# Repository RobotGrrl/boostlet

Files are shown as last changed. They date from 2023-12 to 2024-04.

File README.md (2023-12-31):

# Boostlet!

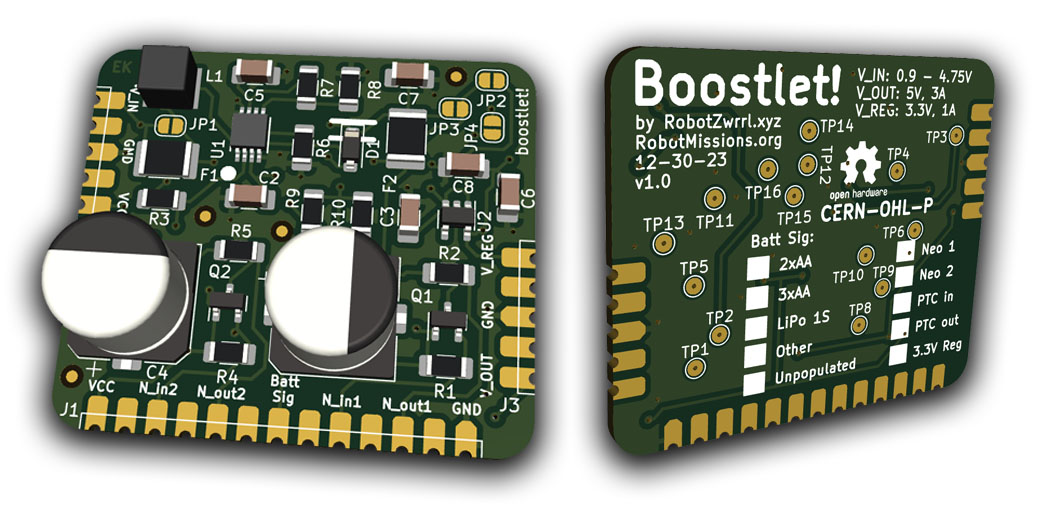
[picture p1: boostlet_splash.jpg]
Boostlet! board 3d view front and back


Embeddable circuit board to boost battery input to 5V intended for small robots. Useful access is provided to two logic level convertors for Neopixels, and a 3.3V regulator. Input and output are protected with PTCs, with the option to not populate with a solder jumper. Castellated connectors enable this circuit board to be added either surface mount or with through-hole 0.1" headers. 

---

## Documentation

[Boost IC: PAM2401](https://www.diodes.com/assets/Datasheets/PAM2401.pdf)

Dimensions: 35 mm x 40 mm

- V_IN: 0.9 - 4.75V
- V_OUT: 5V, 3A
- V_REG: 3.3V, 1A

### Connectors

J1
- VCC
- NEO_IN2
- NEO_OUT2
- BATT_SIG
- NEO_IN1
- NEO-OUT1
- GND

J2 (Input)
- V_IN (V_BATT)
- GND
- VCC

J3 (Output)
- V_OUT (5V)
- GND
- V_REG (3.3V)

### Solder Jumpers
- JP1: Bypass input PTC
- JP2: Enable 3.3V reg powered from 5V boost output
- JP3: Bypass output PTC
- JP4: Connect 3.3V reg output to Vcc _(be sure Vcc isn't connected to anything!)_

_Solder jumpers are open by default, add solder to connect the pads to close them_

Documentation provided under [CC-BY-4.0](https://creativecommons.org/licenses/by/4.0/)

---

## License

Boostlet! (C) Copyright Erin RobotZwrrl, Robot Missions Inc.

12-30-23 v1.0

[RobotZwrrl.xyz/boostlet](http://RobotZwrrl.xyz/boostlet)

[RobotMissions.org](https://RobotMissions.org)

This hardware is released under:

CERN Open Hardware License Version 2.0 - Permissive (CERN-OHL-P)

[https://cern-ohl.web.cern.ch/](https://cern-ohl.web.cern.ch/)

Disclaimer: Distributed as is. No warranty is given. Not responsible or liable for any damage or harm that result from this product.

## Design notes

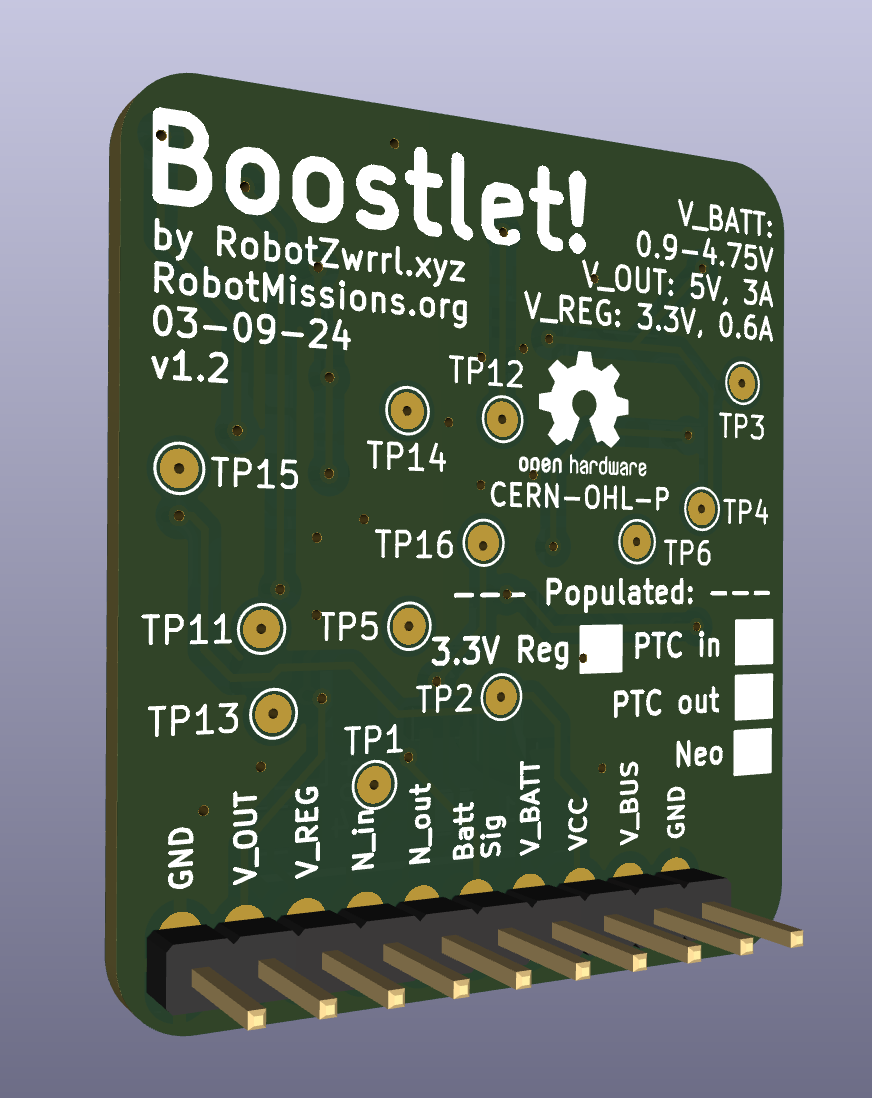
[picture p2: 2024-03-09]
img-back.png

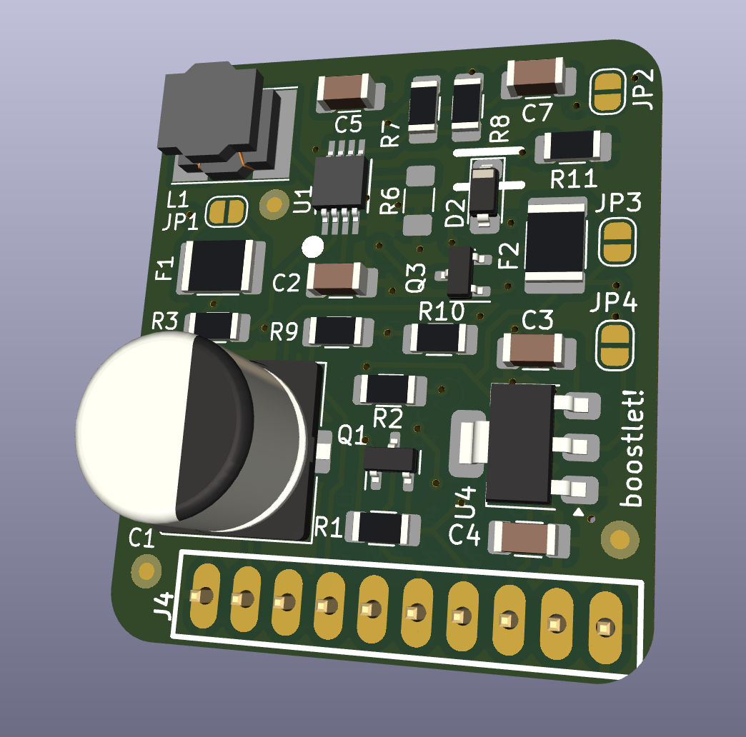
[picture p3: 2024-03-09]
img-front.png

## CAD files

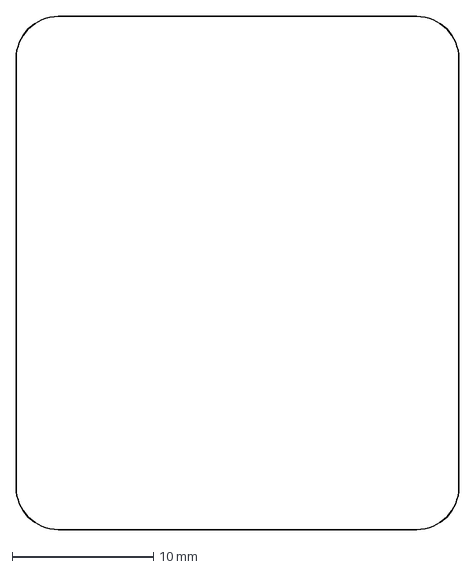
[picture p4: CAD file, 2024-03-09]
outline.dxf
31.4 x 36.4 mm

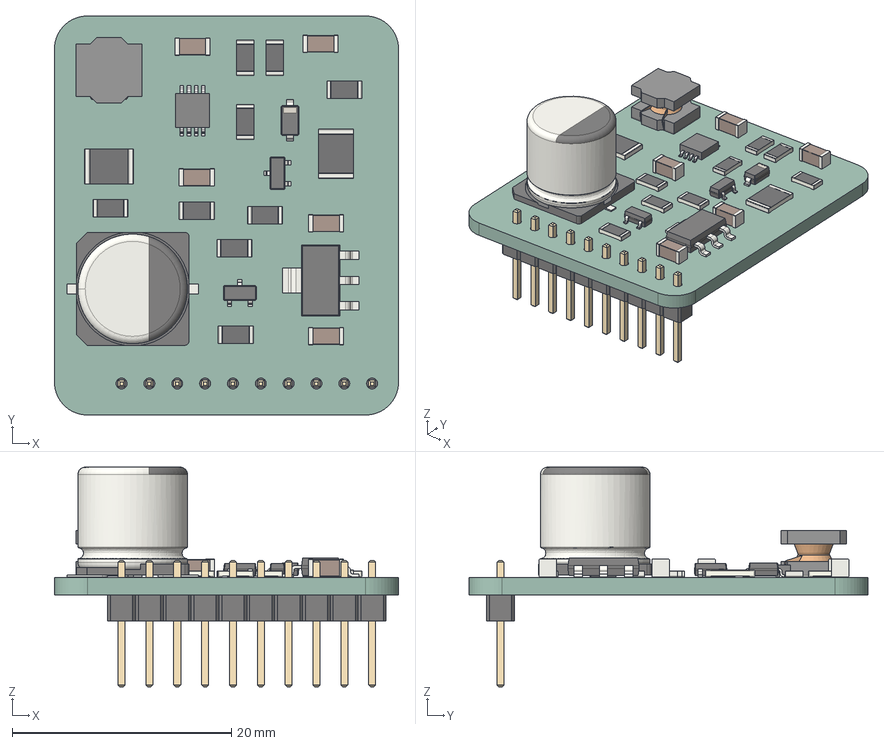
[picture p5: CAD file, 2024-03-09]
boostlet.step
31.4 x 36.4 x 20.0 mm
CP_Elec_10x10
R_1206_3216Metric x 9
SOT_23 x 2
R_1812_4532Metric x 2
C_1206_3216Metric x 5
SOT_223
D_SOD_123
L_Bourns_SRN6045TA
PinHeader_1x10_P254mm_Vertical
boostlet_PCB

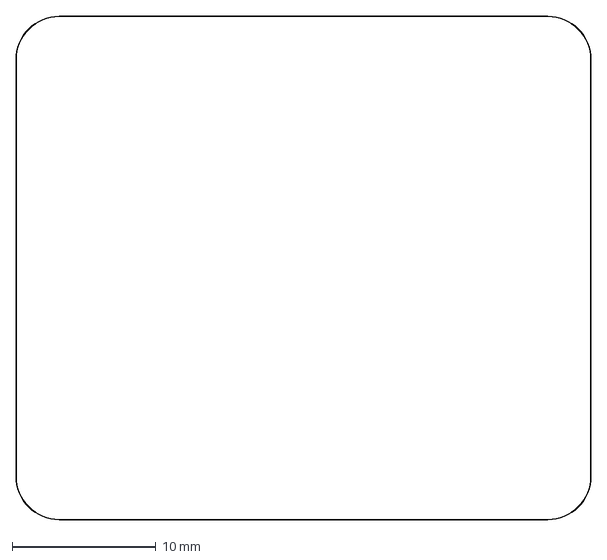
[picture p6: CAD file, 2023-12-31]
boostlet_outline.dxf
40.0 x 35.0 mm

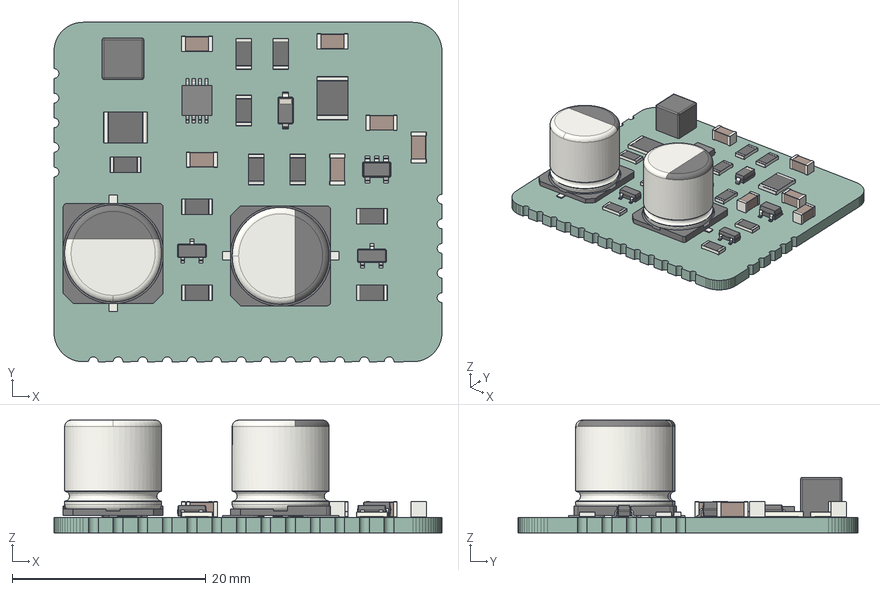
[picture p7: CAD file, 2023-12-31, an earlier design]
archive/v1.0/boostlet.step
40.0 x 35.0 x 11.6 mm
boostlet PCB

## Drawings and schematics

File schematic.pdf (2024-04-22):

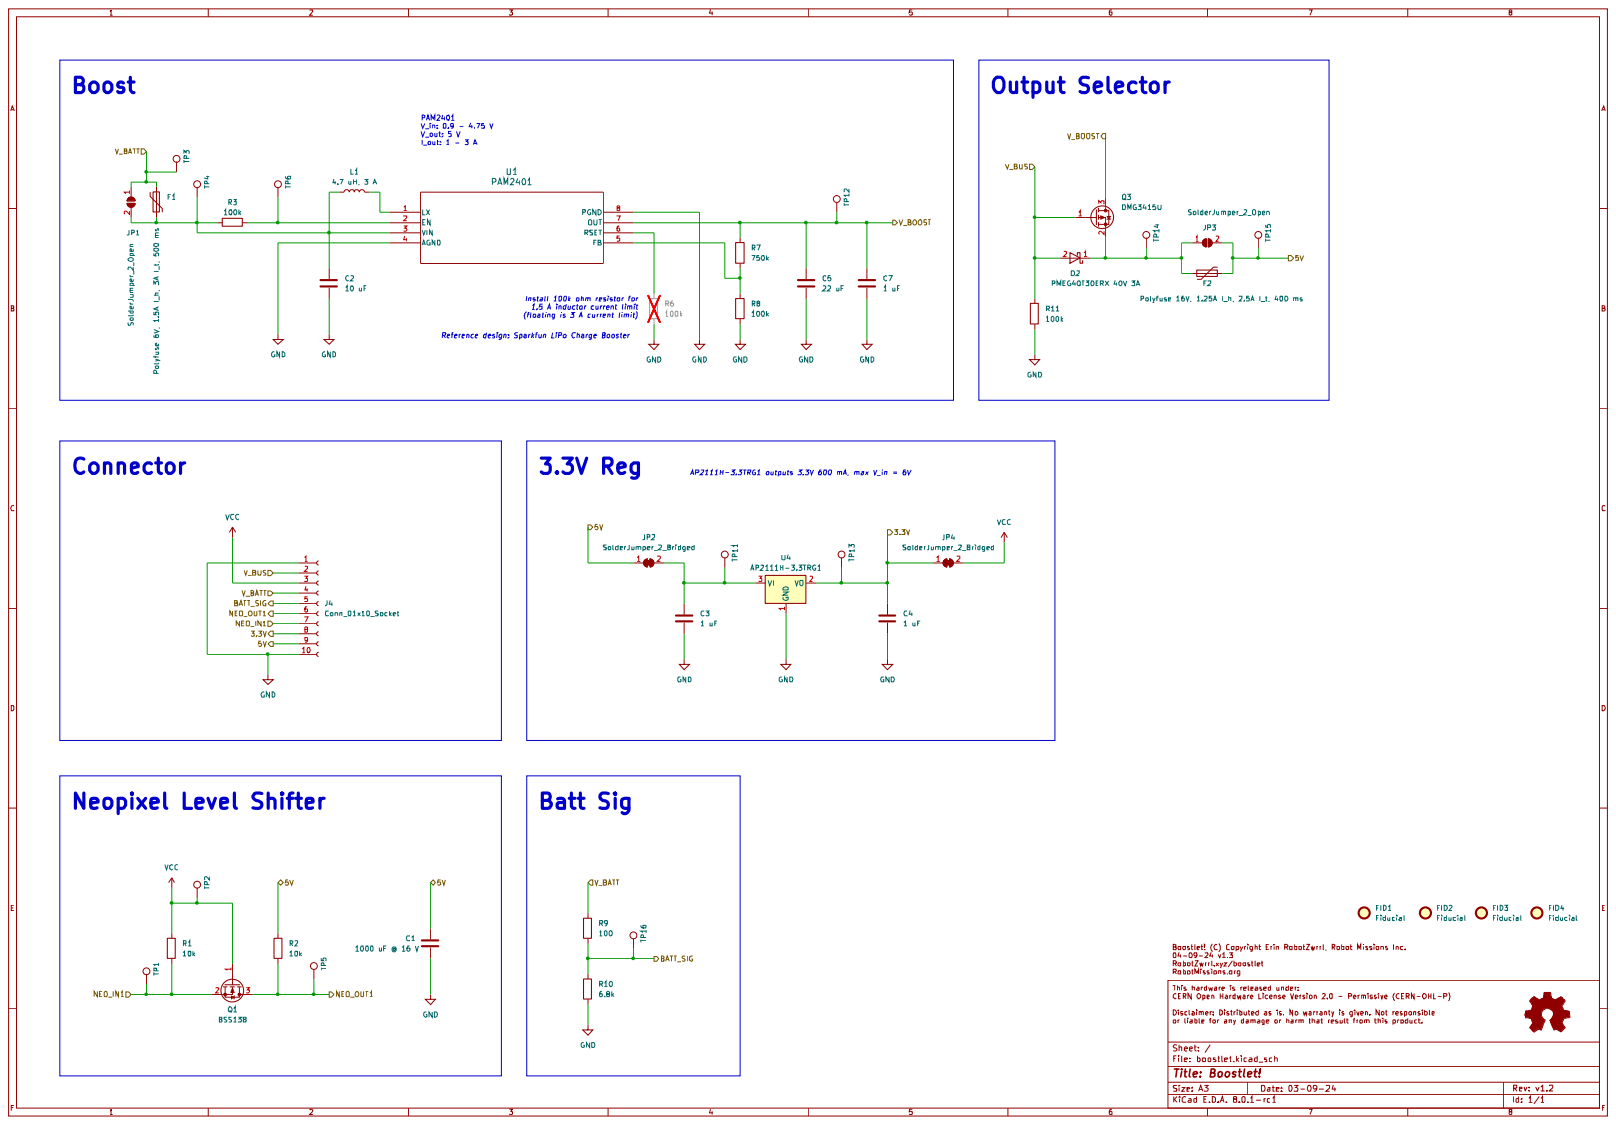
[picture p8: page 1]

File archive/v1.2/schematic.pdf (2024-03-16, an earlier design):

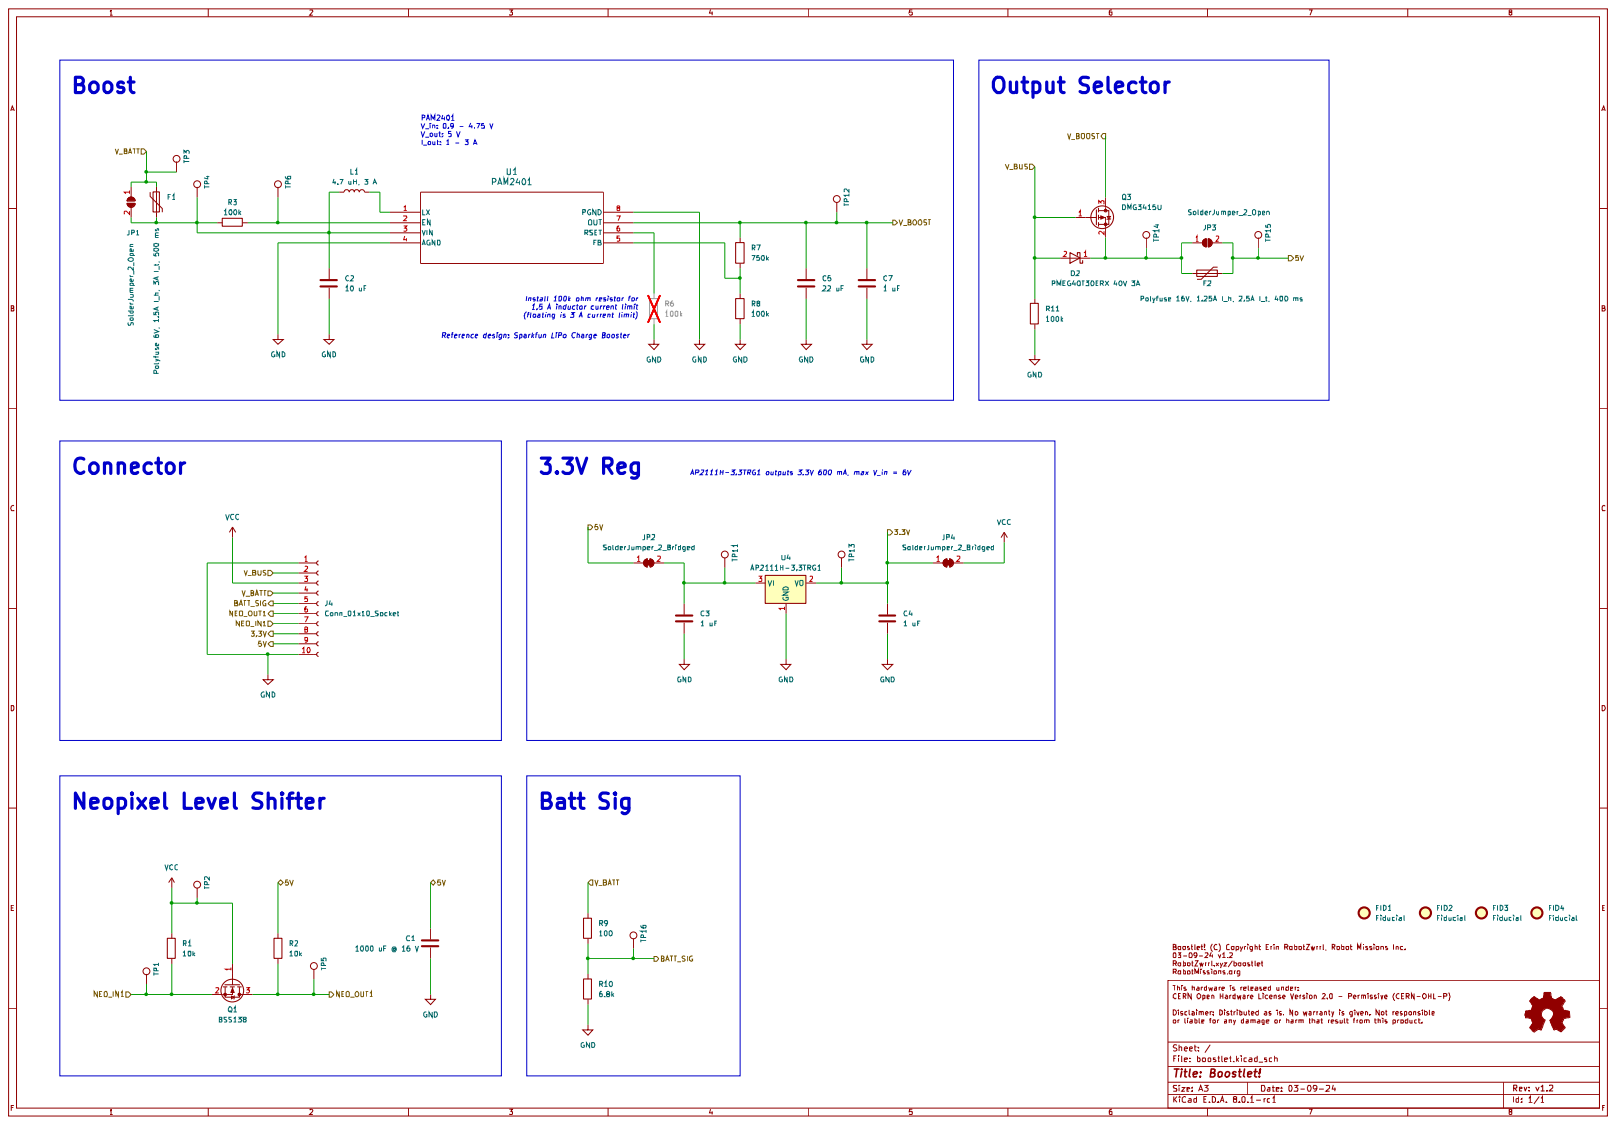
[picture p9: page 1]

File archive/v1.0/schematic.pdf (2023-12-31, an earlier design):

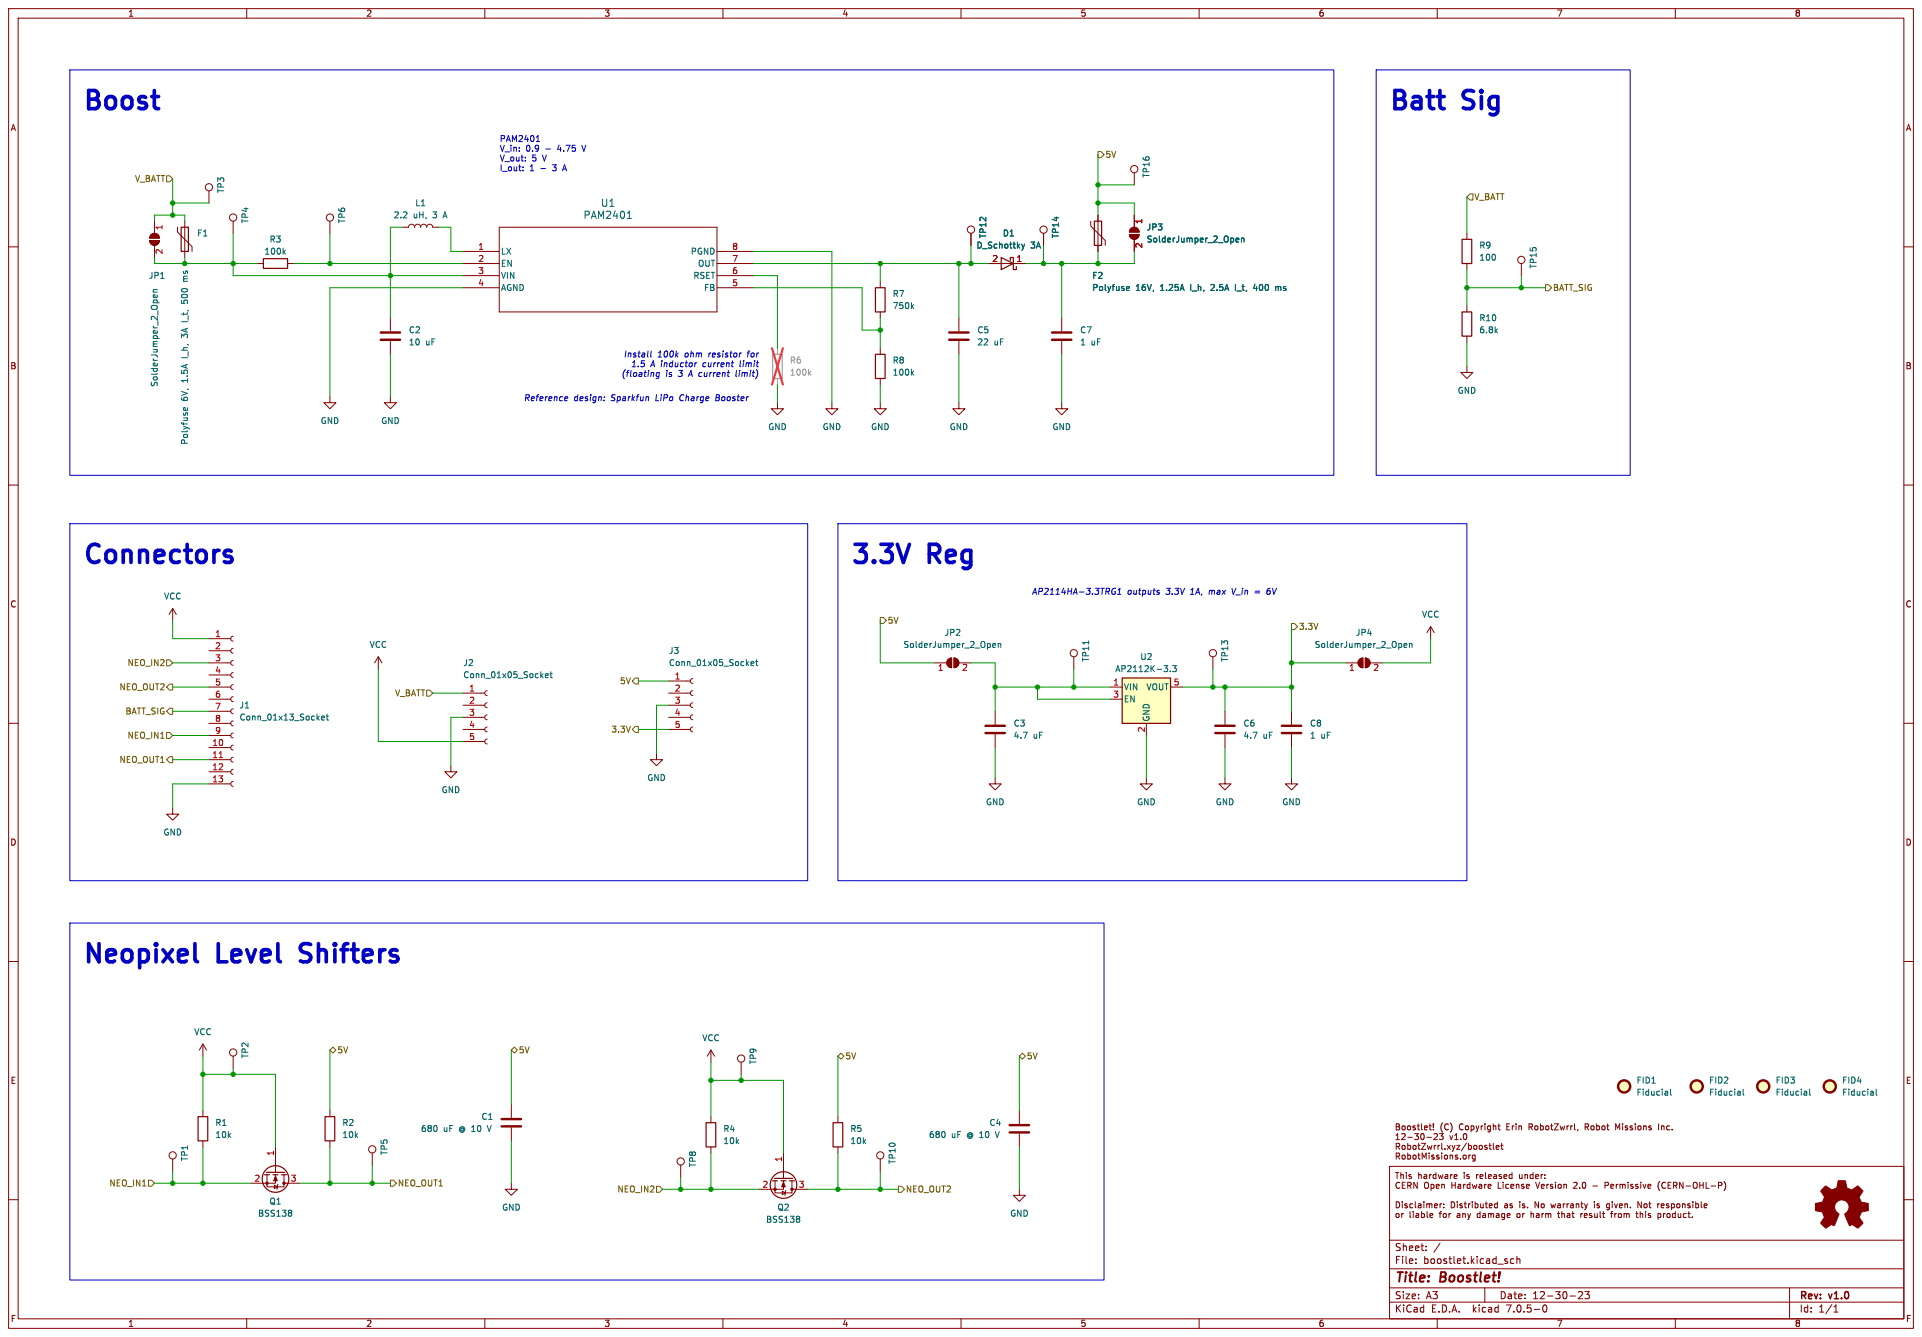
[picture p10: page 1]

or liable for any damage or harm that result from this product.

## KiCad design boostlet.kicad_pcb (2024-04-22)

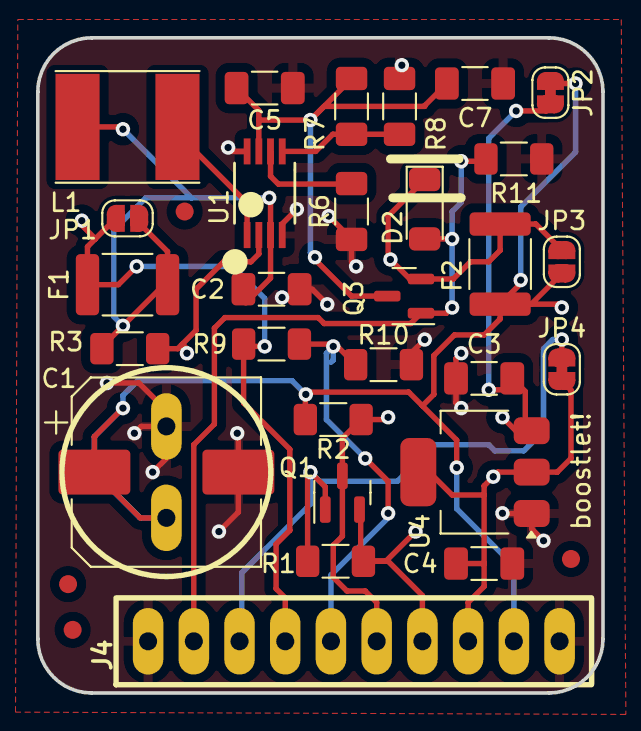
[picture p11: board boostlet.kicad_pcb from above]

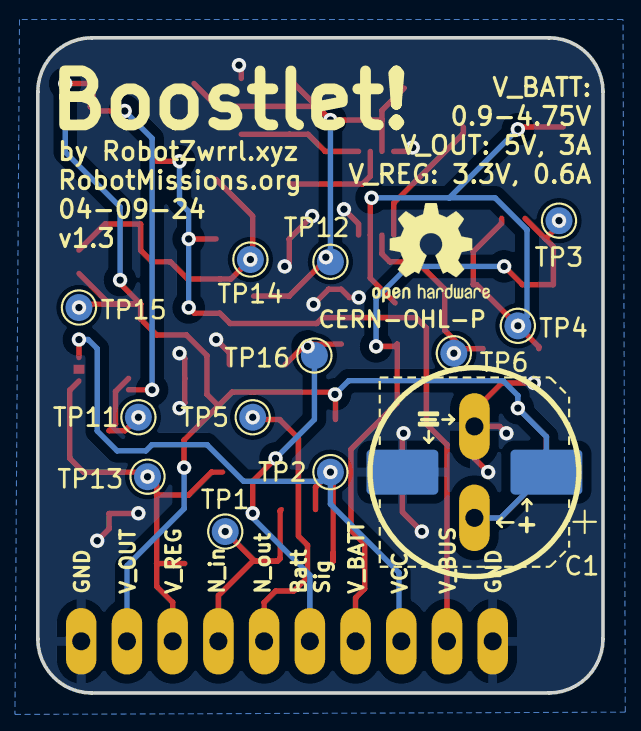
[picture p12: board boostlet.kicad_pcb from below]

Board: 2 copper layers, 31.4 x 36.4 mm, 47 parts (13 on the bottom side), 17 nets.

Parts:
C1, C1#2: 1000 uF @ 16 V; CP_Elec_10x10
C2: 10 uF; C_1206_3216Metric_Pad1.33x1.80mm_HandSolder
C3, C4, C7: 1 uF; C_1206_3216Metric_Pad1.33x1.80mm_HandSolder
C5: 22 uF; C_1206_3216Metric_Pad1.33x1.80mm_HandSolder
D2: PMEG40T30ERX 40V 3A; D_SOD-123
F1: Polyfuse 6V, 1.5A I_h, 3A I_t, 500 ms; Fuse_1812_4532Metric_Pad1.30x3.40mm_HandSolder
F2: Polyfuse 16V, 1.25A I_h, 2.5A I_t, 400 ms; Fuse_1812_4532Metric_Pad1.30x3.40mm_HandSolder
FID1, FID2, FID3, FID4: Fiducial; Fiducial_1mm_Mask2mm
J4: Conn_01x10_Socket; Oval_1x10_P2.54mm
JP1, JP3: SolderJumper_2_Open; SolderJumper-2_P1.3mm_Open_RoundedPad1.0x1.5mm
JP2, JP4: SolderJumper_2_Bridged; SolderJumper-2_P1.3mm_Bridged_RoundedPad1.0x1.5mm
L1: 4.7 uH, 3 A; L_Taiyo-Yuden_NR-60xx_HandSoldering
Q1: BSS138; SOT-23
Q3: DMG3415U; SOT-23
R1, R2: 10k; R_1206_3216Metric_Pad1.30x1.75mm_HandSolder
R3, R6, R8, R11: 100k; R_1206_3216Metric_Pad1.30x1.75mm_HandSolder
R7: 750k; R_1206_3216Metric_Pad1.30x1.75mm_HandSolder
R9: 100; R_1206_3216Metric_Pad1.30x1.75mm_HandSolder
R10: 6.8k; R_1206_3216Metric_Pad1.30x1.75mm_HandSolder
TP1, TP2, TP3, TP4, TP5, TP6, TP11, TP12, TP13, TP14, TP15, TP16: TestPoint; TestPoint_Pad_D1.5mm
U1: PAM2401
U4: AP2111H-3.3TRG1; SOT-223-3_TabPin2
XPIN1: PinHeader_1x01_P2.54mm_Vertical
XPIN2: PinHeader_1x01_P2.54mm_Vertical

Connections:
/3.3V: C4.1, J4.8, JP4.1 (A), TP13.1, U4.2 (VO)
/5V: C1.1, C1#2.1, F2.1, J4.9, JP2.1 (A), JP3.2 (B), R2.1, TP15.1, XPIN1.1
/BATT_SIG: J4.5, R9.2, R10.1, TP16.1
/NEO_IN1: J4.7, Q1.2 (S), R1.2, TP1.1
/NEO_OUT1: J4.6, Q1.3 (D), R2.2, TP5.1
/V_BATT: F1.2, J4.4, JP1.1 (A), R9.1, TP3.1
/V_BOOST: C5.1, C7.1, Q3.3 (D), R7.1, TP12.1, U1.7 (OUT)
/V_BUS: D2.2 (A), J4.2, Q3.1 (G), R11.1
GND: C1.2, C1#2.2, C2.2, C3.2, C4.2, C5.2, C7.2, J4.1, J4.10, R6.2, R8.2, R10.2, R11.2, U1.4 (AGND), U1.8 (PGND), U4.1 (GND), XPIN2.1
unnamed: D2.1 (K), F2.2, JP3.1 (A), Q3.2 (S), TP14.1
unnamed: C2.1, F1.1, JP1.2 (B), L1.1, R3.1, TP4.1, U1.3 (VIN)
unnamed: C3.1, JP2.2 (B), TP11.1, U4.3 (VI)
unnamed: R3.2, TP6.1, U1.2 (EN)
unnamed: R7.2, R8.1, U1.5 (FB)
unnamed: L1.2, U1.1 (LX)
unnamed: R6.1, U1.6 (RSET)
VCC: J4.3, JP4.2 (B), Q1.1 (G), R1.1, TP2.1

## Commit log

2023-12-31 Circuit board and schematic
    [boostlet.kicad_pcb, boostlet.kicad_sch, boostlet.step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]
2024-03-09 Archive v1.0
    [boostlet.kicad_pcb, boostlet.kicad_sch, boostlet.step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]
2024-03-09 Version 1.2
    [boostlet.csv, boostlet.kicad_pcb, boostlet.kicad_sch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]
2024-03-10 Information update
    [boostlet.kicad_sch]
2024-03-16 Mysterious vault of boostletland
    [boostlet-B_Cu.gbl, boostlet-B_Mask.gbs, boostlet-B_Paste.gbp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]
2024-03-16 Boostlet v1.2
    [boostlet.kicad_pcb, boostlet.kicad_sch]
2024-04-22 Mlep mlep rrrrr, zwap zwap zwap
    [boostlet-B_Cu.gbl, boostlet-B_Mask.gbs, boostlet-B_Paste.gbp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]
